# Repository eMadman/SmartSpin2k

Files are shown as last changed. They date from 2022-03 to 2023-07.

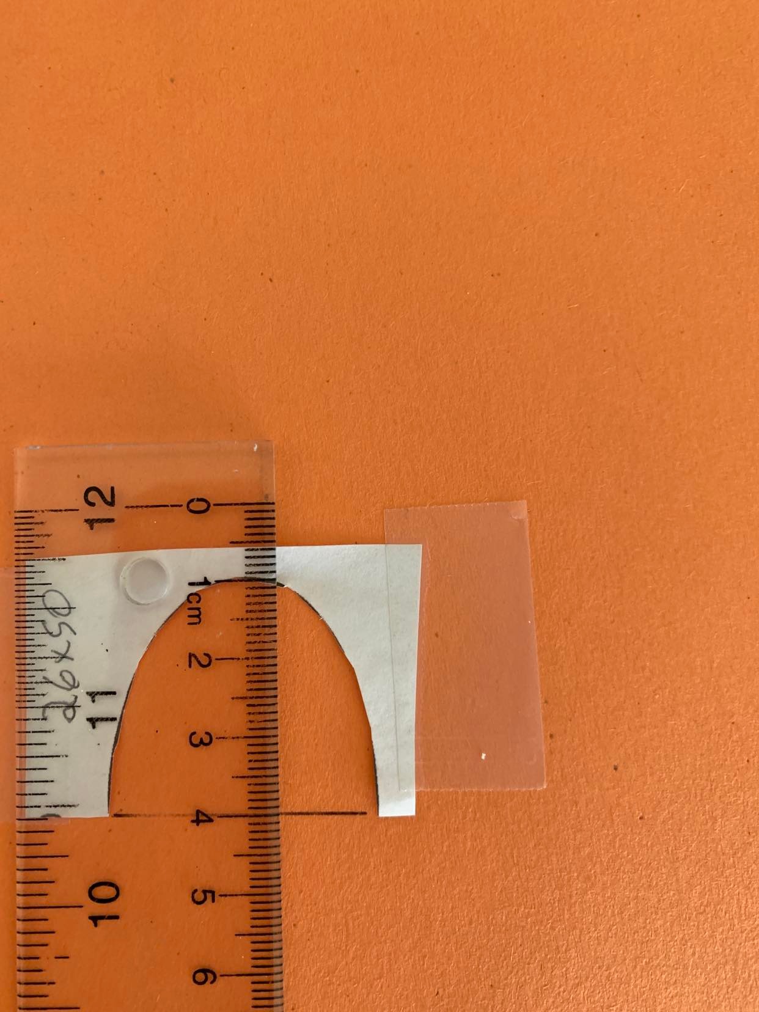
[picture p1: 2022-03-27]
Hardware/MODS/Direct Mount Mod/Bike Mount/reference photos/LeMond Revmaster/cut to fit 2.jpg

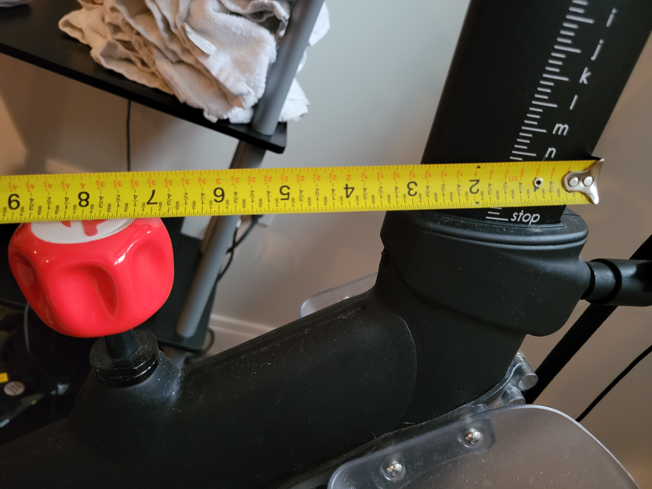
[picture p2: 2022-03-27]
Hardware/MODS/Direct Mount Mod/Bike Mount/reference photos/Peloton/20220217_082631.jpg

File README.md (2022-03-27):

ss2k banner

SmartSpin2k is an easy to build open source project that lets you turn any Spin Bike into a Smart Trainer. SmartSpin2k uses an ESP32 and stepper motor to let fitness apps like Zwift automatically control spin bikes that have a resistance knob. The SmartSpin2k also has shifter buttons that allow the user to simulate shifting gears on the stationary bike. 

Since SmartSpin2k is easy to manufacture, build one for yourself, build some for your friends, or setup a print farm and build them for everybody - we're an open community and welcome all levels of involvement!

## Important announcement for existing users
We have identified an issue with auto updates.  After a factory reset, you will not be able to access the configuration screen.  We advise users to flash the latest version of the 2.2.8 firmware, [available here](https://github.com/doudar/SmartSpin2k/releases).  Flashing instructions are available on the [Wiki](https://github.com/doudar/SmartSpin2k/wiki/Loading-Software)

### Documentation
Everything you need to know is in the [SS2K Wiki](https://github.com/doudar/SmartSpin2k/wiki)

If you'd like to get involved in SS2K but don't want to build your own, a limited number of kits are available on sale by our community members.  [Click here](https://github.com/doudar/SmartSpin2k/wiki/Prebuilt-Kits) for more information

Hardware 2.0 

[_^^@eMadman's IC4 model_](https://github.com/doudar/SmartSpin2k/tree/develop/Hardware/MODS/Case%20V2%20-%20Schwinn%20IC4%20Mod)

## Contributing
1. Install Microsoft Visual Code. https://code.visualstudio.com/
2. Install PlatformIO into Visual Code. https://platformio.org/platformio-ide
3. Install Pre-commit. https://pre-commit.com
4. Install pre-push git hooks: `pre-commit install --hook-type pre-push`
5. Open this project in PlatformIO.

## Licensing
The hardware designs in this project are licensed under the [CERN Open Hardware License Version 2 - Permissive license](Hardware/LICENSE).
The software in this project is licensed under the [GNU GENERAL PUBLIC LICENSE Version 2, June 1991 license](LICENSE).

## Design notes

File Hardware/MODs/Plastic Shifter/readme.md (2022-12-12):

Required hardware:

* 4x M3x20
* 4x heatset inserts - 5mm diameter
* 2x 12mm momentary shifters
* 1x Female headphone connector
* 1x Male to Male headphone cable
* 2x 1/4" velcro straps

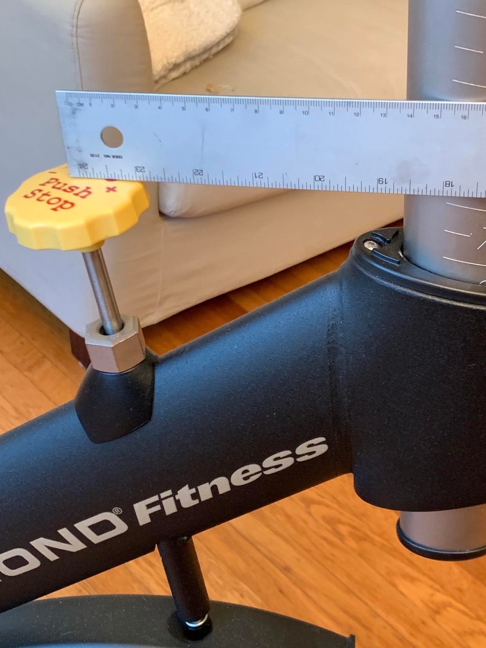
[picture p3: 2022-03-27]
Hardware/MODS/Direct Mount Mod/Bike Mount/reference photos/LeMond Revmaster/273752718_268677505408959_7329679807537366636_n.jpg

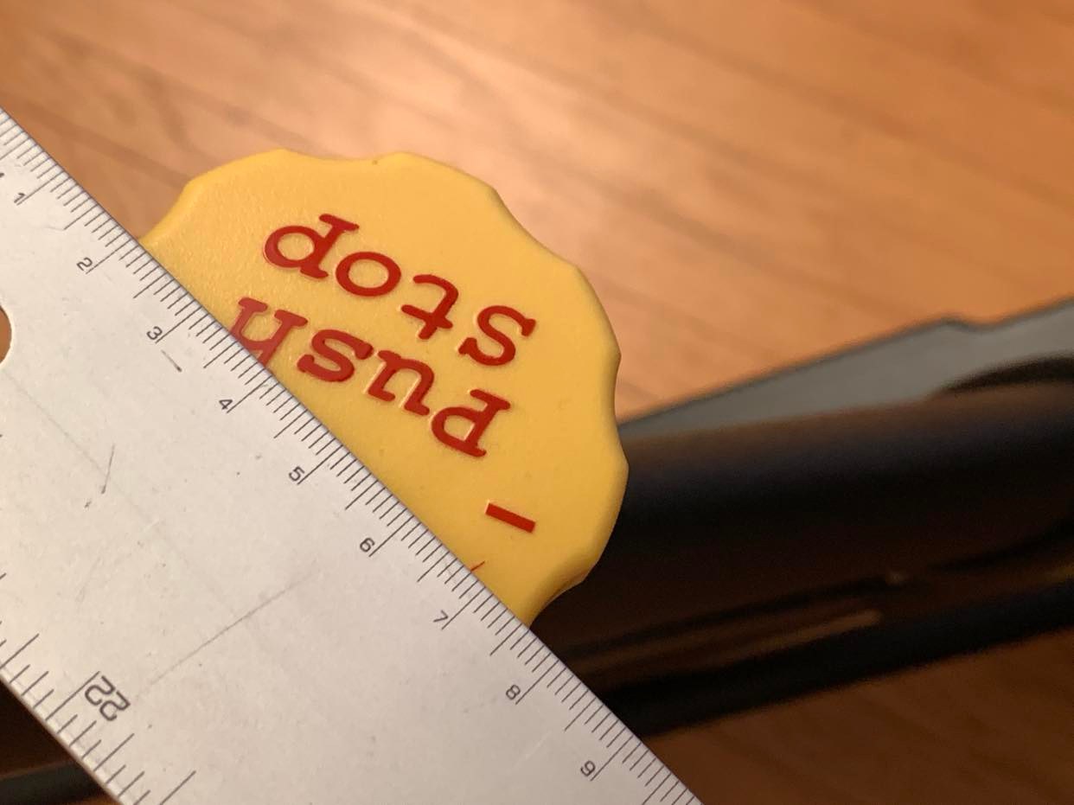
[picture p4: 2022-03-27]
Hardware/MODS/Direct Mount Mod/Bike Mount/reference photos/LeMond Revmaster/259313492_315241787087385_651882542709975977_n.jpg

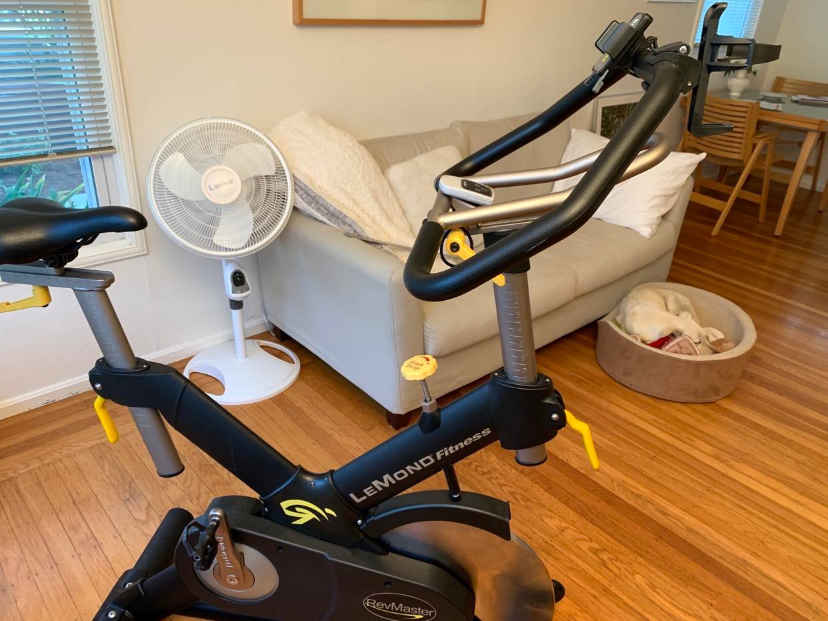
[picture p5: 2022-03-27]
Hardware/MODS/Direct Mount Mod/Bike Mount/reference photos/LeMond Revmaster/272849360_1012936169320139_2908520262834072954_n.jpg

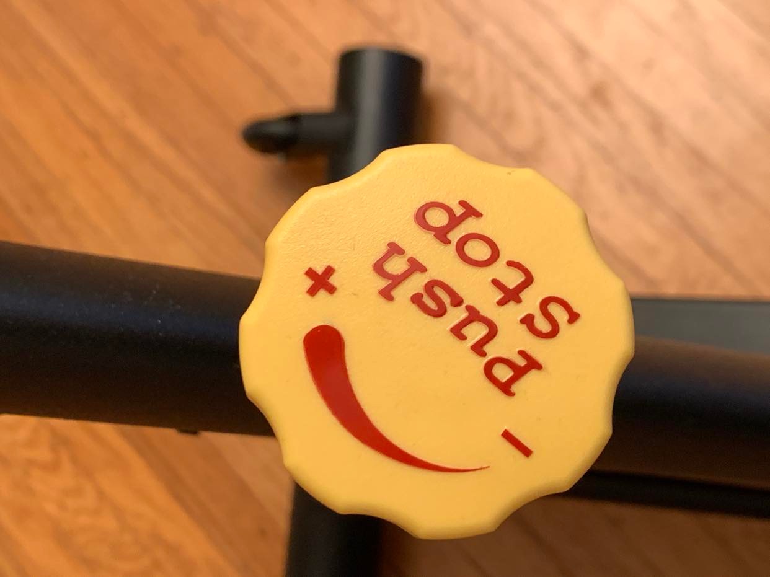
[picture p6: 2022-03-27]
Hardware/MODS/Direct Mount Mod/Bike Mount/reference photos/LeMond Revmaster/270647746_495659278598530_319794024257236569_n.jpg

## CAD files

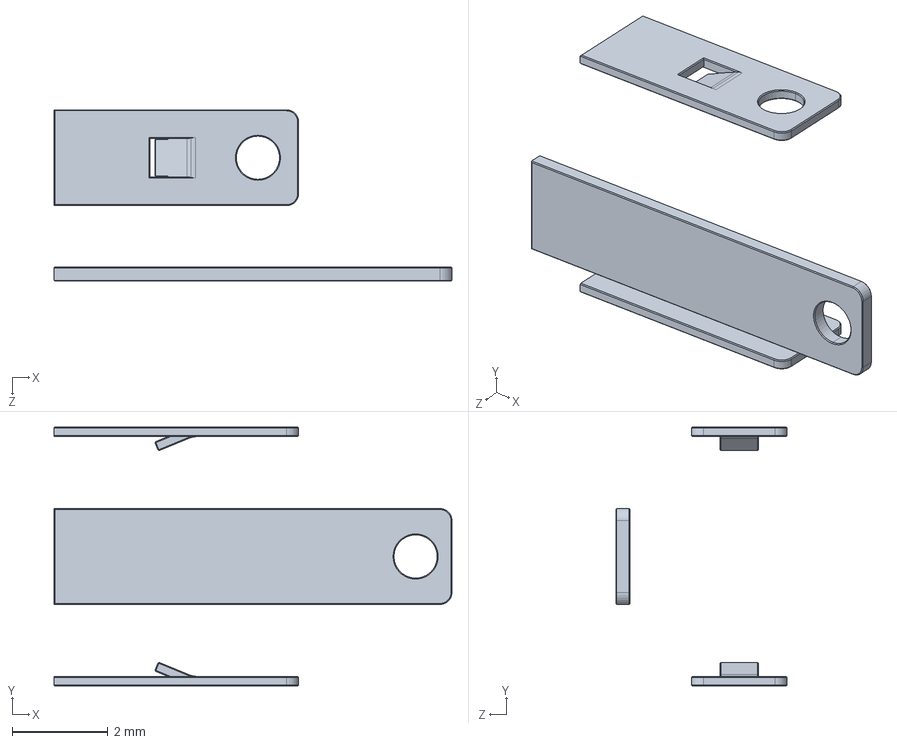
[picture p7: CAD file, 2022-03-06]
Hardware/MODS/Case V2 - Ultra Short Mod/Case/CAD/Connectors/3.5mmJack.SLDASM
8.30 x 5.40 x 3.58 mm

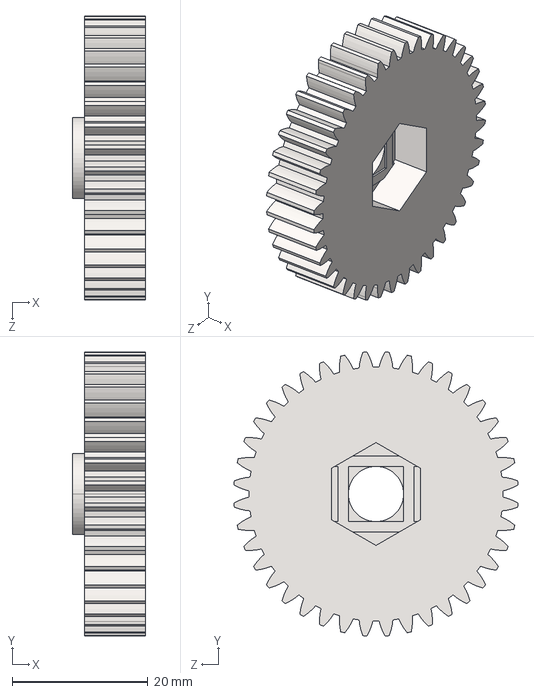
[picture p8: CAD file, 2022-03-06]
Hardware/Case Version2/Gears/CAD/Spur gear 1M 40T Hex.STEP
10.8 x 41.9 x 41.9 mm

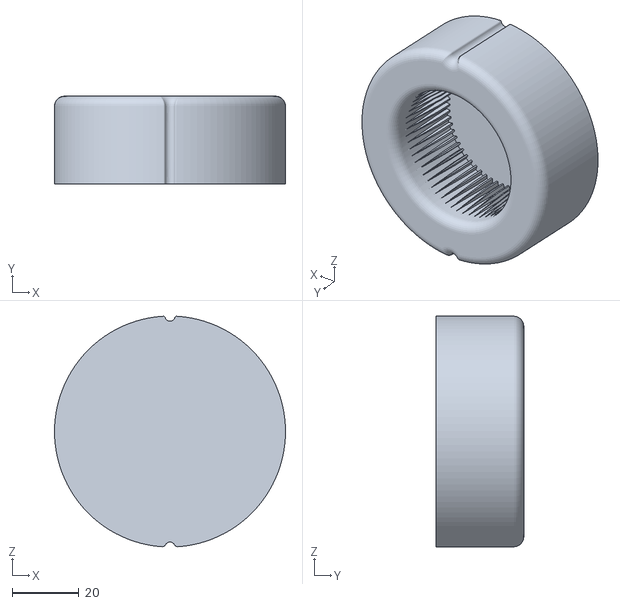
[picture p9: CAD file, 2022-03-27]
Hardware/Inserts/Star Trac 2010.stl
69.0 x 26.2 x 68.9

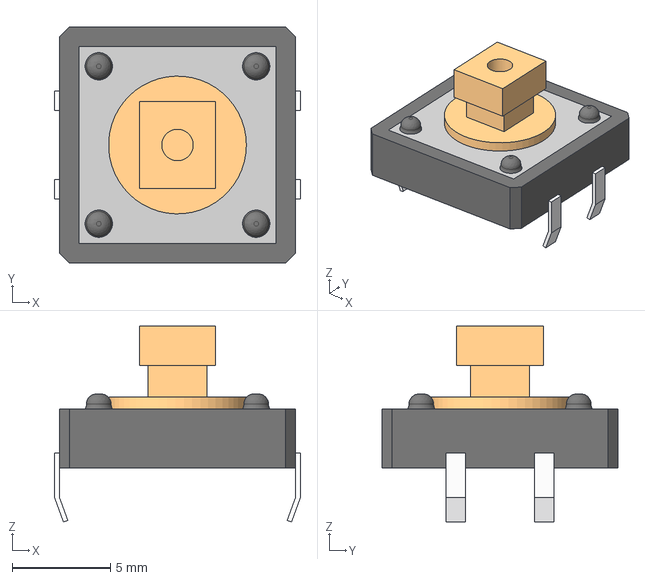
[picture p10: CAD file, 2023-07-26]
Hardware/MODS/39.4mm motor/Case/Case/CAD/PCB Switch 01.step
12.5 x 12.0 x 9.95 mm

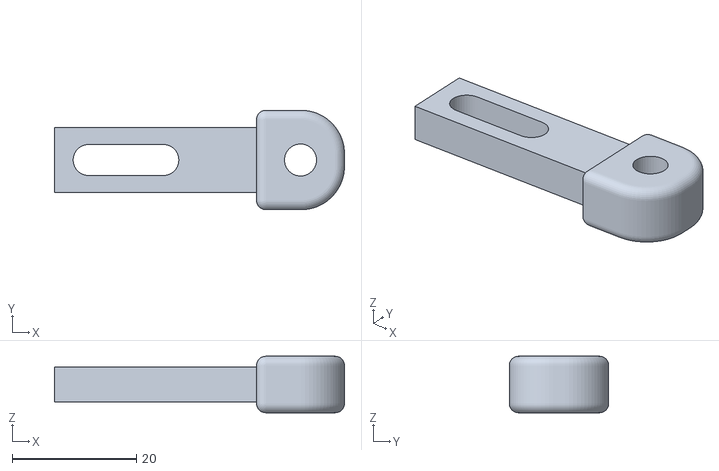
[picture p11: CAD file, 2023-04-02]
Hardware/MODS/Adjustable Arm/Bowflex C7.stl
46.7 x 16.0 x 9.10

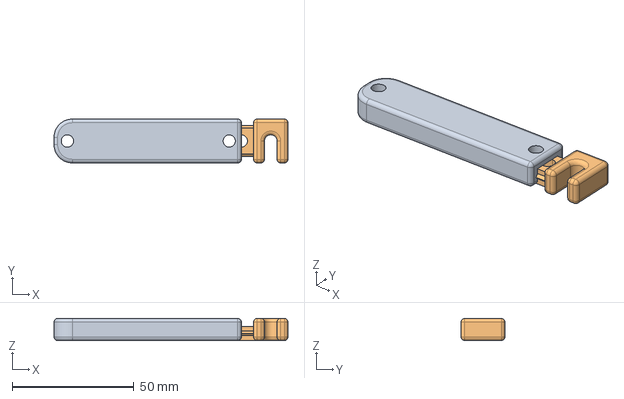
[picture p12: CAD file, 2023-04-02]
Hardware/MODS/Adjustable Arm/CAD/Peloton.step
96.2 x 18.0 x 9.10 mm

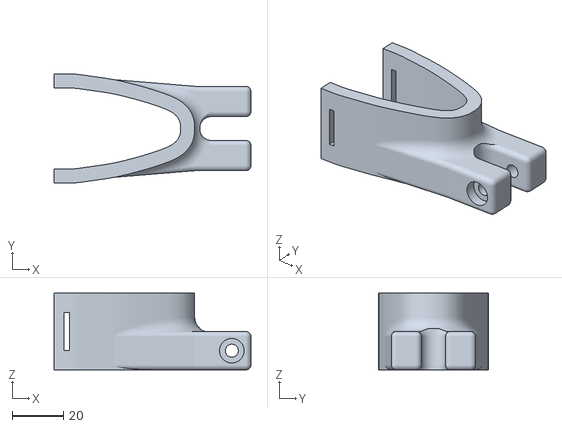
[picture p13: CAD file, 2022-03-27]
Hardware/MODS/Direct Mount Mod/Bike Mount/Peloton.stl
77.0 x 42.8 x 30.0

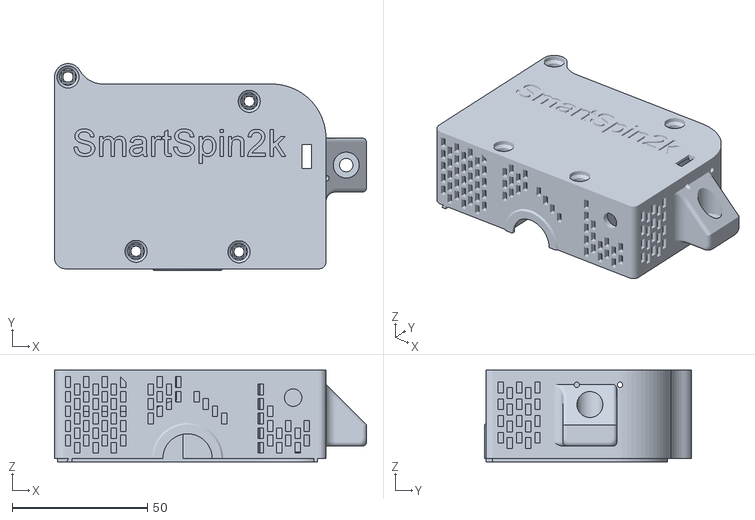
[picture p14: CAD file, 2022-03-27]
Hardware/MODS/Direct Mount Mod/Case/body-right.stl
115.5 x 76.6 x 33.9

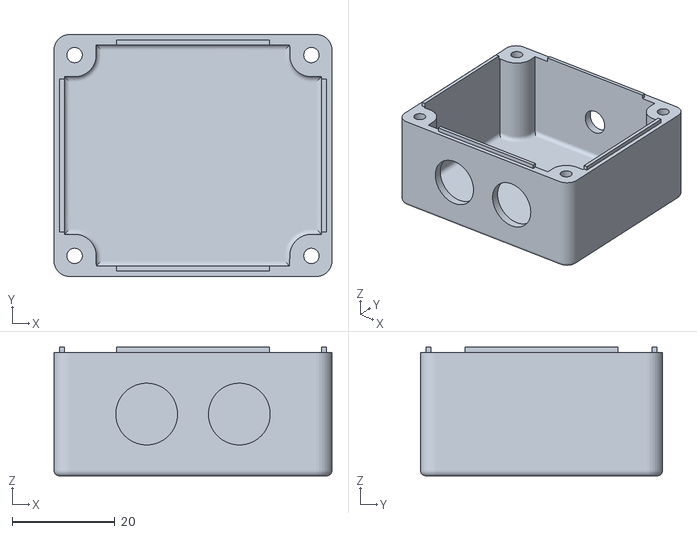
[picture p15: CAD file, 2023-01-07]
Hardware/MODs/Plastic Shifter/Body.stl
54.0 x 47.0 x 25.0

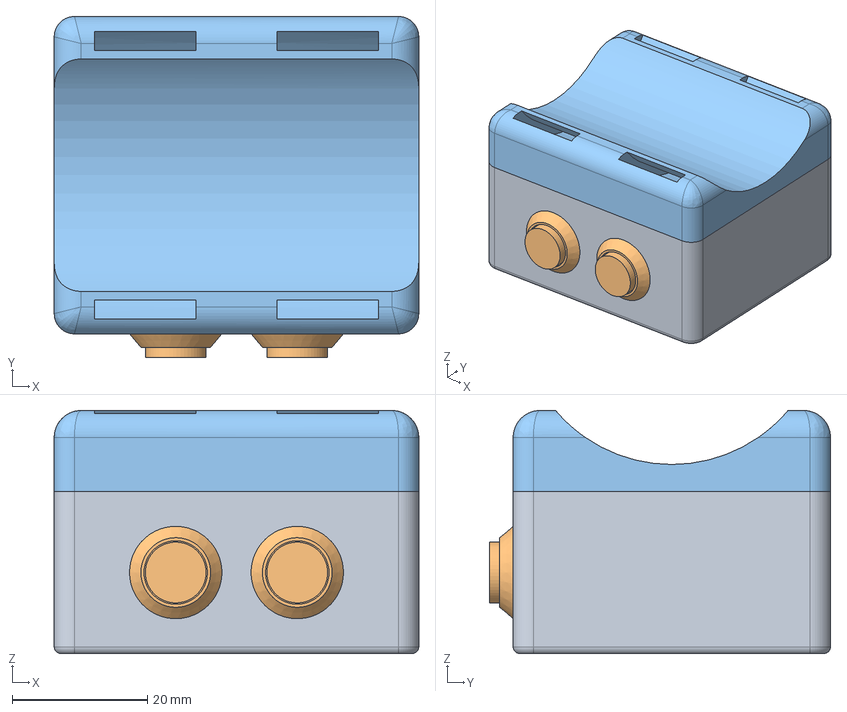
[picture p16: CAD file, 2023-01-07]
Hardware/MODs/Plastic Shifter/CAD/ABS Shifter v9.step
54.0 x 50.5 x 36.0 mm
Button
lid

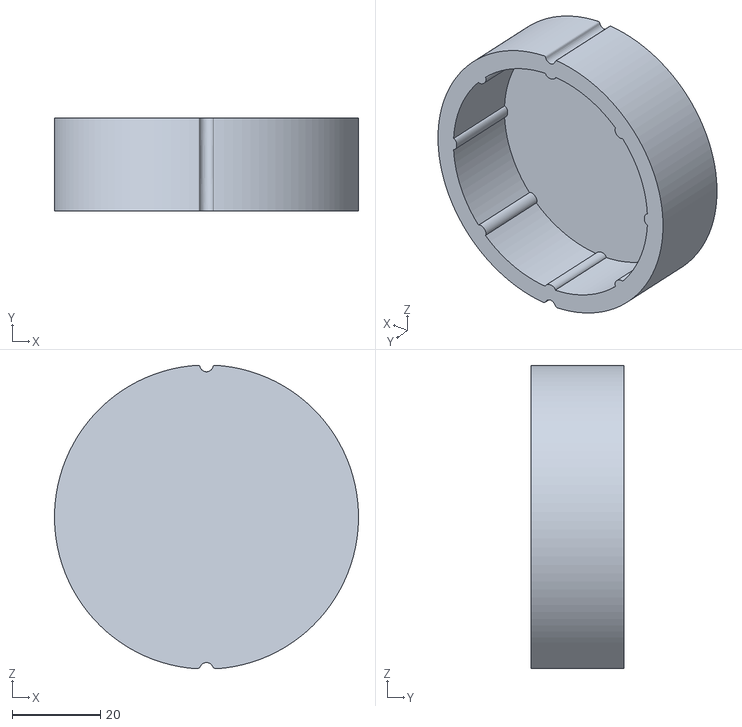
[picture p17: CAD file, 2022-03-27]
Hardware/Inserts/Le Mond Revmaster.stl
69.0 x 21.2 x 68.9

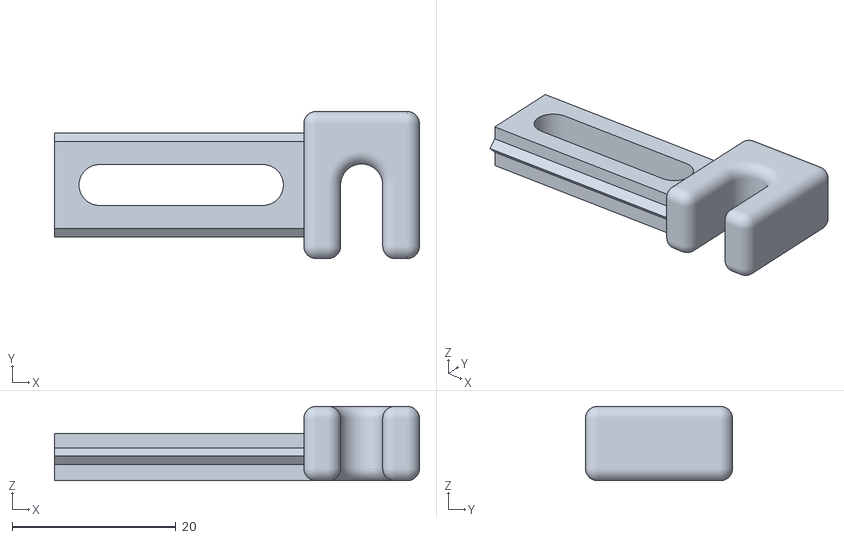
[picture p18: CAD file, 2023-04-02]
Hardware/MODS/Adjustable Arm/_arm hook.stl
44.7 x 18.0 x 9.10

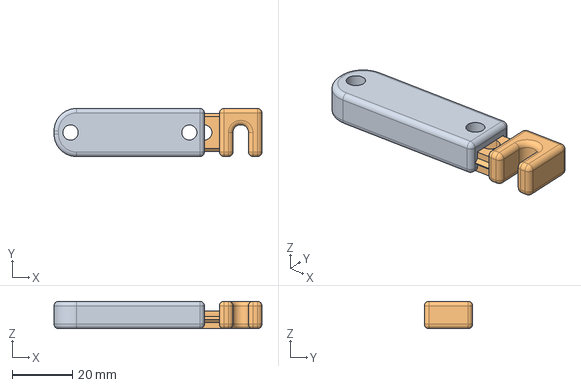
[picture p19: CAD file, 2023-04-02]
Hardware/MODS/Adjustable Arm/CAD/_ss2k arm - reference v4 v7.step
69.2 x 16.0 x 9.10 mm

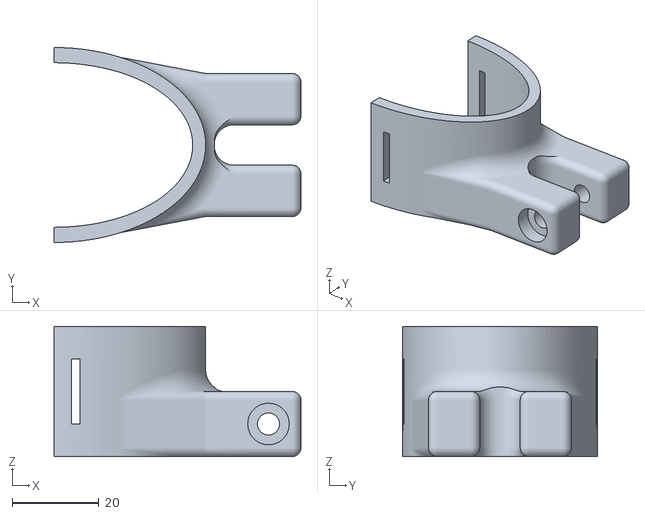
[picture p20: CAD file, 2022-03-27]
Hardware/MODS/Direct Mount Mod/Bike Mount/LeMond Promaster.stl
57.0 x 45.0 x 30.0

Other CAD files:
Hardware/MODS/39.4mm motor/Case/Case/CAD/Connectors/54-00063_ASM.SLDASM
Hardware/MODS/39.4mm motor/Case/Case/CAD/Connectors/3.5mmJack.SLDASM
Hardware/MODS/39.4mm motor/Case/Case/CAD/Connectors/54-00063-4.SLDPRT
Hardware/MODS/39.4mm motor/Case/Case/CAD/Connectors/54-00063-8.SLDPRT
Hardware/Case Version2/Gears/CAD/Spur gear 1M 40T Hex.SLDPRT
Hardware/Case Version2/Gears/Spur gear 1M 40T Hex.STL
Hardware/MODS/39.4mm motor/Case/Case/CAD/Body_Drawing.SLDPRT
Hardware/MODS/39.4mm motor/Case/Case/CAD/Body_Drawing_Left.SLDPRT
Hardware/MODS/39.4mm motor/Case/Case/CAD/Body_Drawing_Left.STEP
Hardware/MODS/39.4mm motor/Case/Case/CAD/Body_Drawing_Right.SLDPRT
Hardware/MODS/39.4mm motor/Case/Case/CAD/Body_Drawing_Right.STEP
Hardware/MODS/39.4mm motor/Case/Case/CAD/Connectors/54-00063-1.SLDPRT
Hardware/MODS/39.4mm motor/Case/Case/CAD/Connectors/54-00063-3.SLDPRT
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

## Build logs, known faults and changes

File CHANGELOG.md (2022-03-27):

# Changelog

All notable changes to this project will be documented in this file.

The format is based on [Keep a Changelog](https://keepachangelog.com/en/1.0.0/)
and this project adheres to [Semantic Versioning](https://semver.org/spec/v2.0.0.html).

## [Unreleased]

### Added

- Added a test for wifi connectivity and a function to repair the connection.
- Added a new WIFI_Control class.

-

### Changed

- Pruned a couple unused functions from main.
- Updated to Esp32 Arduino master.
- Changed BLE tasks back to core 1.
- Increased stack size on both BLE tasks as well as the HTTP server task.
- updated CA for OTA updates

### Fixed

### Hardware

- Short Mod, increased screw hole size from 4.0mm to 4.2mm.
- Short Mod, moved plug wall offset from 1.8mm to 2.0mm.
- Increased shaft diameter of 40T hex gear by .15
- Increased bolt head diameter of 40T hex gear by .15
- added chamfer to screw posts in case body (direct mount mod)

## [2.2.8]

### Added

- Added screenshot for wiki main page
- Added functions to start and stop WiFi and Http server.
- Added Additional logging to the custom characteristic.
- Added option to enable/disable UDP logging. Default is disabled.
- Added Wiki links to most SS2K pages. [see #314](https://github.com/doudar/SmartSpin2k/issues/314)
- Added WebSockets for logging [see #173](https://github.com/doudar/SmartSpin2k/issues/173)
- Reworked logging to run log-appender outside the worker task (task no longer blocked by logger traffic).
- WebsocketsAppender can handle multiple (up to 4) clients. Status.html will reconnect if connection to websockets server is disconnected.

### Changed

- Refactored ERG.
- Reset to Default must be confirmed [see #51](https://github.com/doudar/SmartSpin2k/issues/51)
- Update Firmware: Upload dialog accepts .bin, .html and .css files. [see #98](https://github.com/doudar/SmartSpin2k/issues/98)
- Removed conflicting secondary BLE indicate when a shift was preformed via the custom characteristic.
- Default stepper power is now used on reset to defaults.
- Refactored Main and HTTP Server.
- Changed from hard coding to Enums in BLEServer.
- Added simulateWatts to ERG mode internal check.
- Increased BLE Stack(s) and reduced ERG stack.
- Disabled shifter ISR while ERG is running.
- Fixed possible infinite loop in ERG when stepper never reached target position due to being past min or max position.
- When UDP logging is enabled, html will no longer request logging info.
- Increased remote server minimum packet delay to 325ms and max to 700ms.
- Updated Arduino_esp32 to the latest 2.0.2 version.
- Fixed all libraries to static releases.
- Reduced max_connect_retries from 10 to 3.
- Increased max_scan_retries from 1 to 2.
- Now only send notifications for subscribed characteristics.
- Increased JSON size for userConfig (hopefully fix config saving issues).
- Changed LOGE messages in spiffs logging to regular LOG messages so they will display via network logging.
- Complete BLE Client connection code rebase.

### Fixed

- bluetoothscanner.html now lists fitness machine services in the PM list.
- Fixed bug in external control.

### Hardware

- Added Ultra Short Case mod which should allow as little as ~40mm from knob center to head tube.
- Revised shifter for easier printing.  Updated printing instructions.
- moved original shifter design into Archive directory

#### Direct mount Mod

- IC4 Mod renamed to Direct Mount Mod.  Several directories have changed.
- bike mount and arm added for Echelon Connect Sport
- Arm design revised for added stiffness
- Case, arm and bike mount separated into individual CAD files for easier edits.
- Arm and bike mount re-drawn in CAD.  It should be much easier to create designs for new bikes now.
- Added direct mount for Revmaster and Peloton bikes
- New insert for Startrac

## [1.12.30]

### Added

- Added userConfig shifterDir to change direction of shifters in software to compensate for wiring
- Added userConfig StepperDir to change direction of stepper in software to compensate for wiring
- Added backend and html for shifter and stepper directions.
- Added parameters for auto homing.

### Changed

- Fixed a couple bugs in PowerTables
- Fixed BLE Scanner webpage not displaying devices.
- Corrected a check in the FTMS write control point indication.
- readme copy change
- added bridging improvements for screw holes - in cad but missing in STL

### Hardware

-

#### IC4 Mod

-

## [1.12.26]

### Added

- Added Webpage for Shifting.
- Added /shift server on backend.
- Split userConfig into userConfig and rtConfig.
- Added ERG testing to btsimulator.html
- Broke out ERG computation into it's own task.
- Added image for wiki.
- Replaced existing shifter housing with new and improved 2 in 1 revision

### Changed

- Adjusted the order of "Submit" "Reboot" and "Reset to Defaults" on the settings page.
- Adjusted the setting webpage so "reset to defaults" is harder to accidentally press.
- Increased the amount of free stack by removing the default Arduino loop();
- Updated /shift server on to rtConfig.
- Fixed redeclaring global targetposition in moveStepper().
- Renamed Settings page "Submit" button to "Save Setting"

### Hardware

- Increased hex head and nut size to 13mm.
- Increased depth on Knob Cup 2mm so a thicker nut can be used.
- Added assembly .gif images.

#### IC4 Mod

- NEW: Hex bolt mod for 40t gear and matching ic4 cup/mount. This is a drop-in replacement for the plastic printed gear + cup/holder combination. This adds a lot of strength
- Renamed directory to something more apparent.
- Removed need for support material from case.
- Thicker slide design which removes need for washers.
- Slightly shorter slide - should allow more flexibility for ss2k placement on IC4.
- Tighter tolerances on case and bike mount for slide fitting. It should be a tight enough to prevent accidental removal
- Slightly larger diameter holes for m3 screws used in case assembly. Screws should be much easier to insert
- Additional tolerance for m5 fitting.
- Combined knob cup & knob insert for schwinn to reduce amount of plastic needed for the schwinn.
- Including a revised 11t stl - A bit more clearance on inner diameter the drive shaft on my steppers.

## [1.12.2]

### Added

- Firmware update will now download only spiffs files if missing without updating the firmware.
- New UDP logger by @MarkusSchneider .
- Added custom IC4 build and mount by @eMadman .

### BugFixes

- Power Correction factor now minimum .5 maximum 2.5 and added checks to stay within limits.
- 404 now redirects to index file handler.
- settings_processor now checks shiftsteps field to determine if it's on the main settings page.

## [1.11.24]

### Added

- Moved FTMS callback decoding outside of the callback.
- Revamped the way notify buffer works as it was causing a memory leak.
- BLE Custom Characteristic motor driver calls now apply settings received.
- Motor current now automatically scales if ESP32 temp starts getting too high.
- Added comments after compiler #endif Statements to make it easier to see what the partner #if statement is.
- Added BLE_syncMode to support syncing shifterPosition with bikes that also report their resistance level.
- Added git tag to prevent branch from downgrading to the last release.
- Added Hardware Version 2.0.
- MCWPWM for stepper control.
- Erg Sensitivity control added.
- Function to stop motor and release tension if the user stops pedaling in ERG mode.  
- Received BLE is now buffered and then processed.
- Added Fitness Machine supported inclination range characteristic.
- Additional unit tests.

### Changed

- Renamed BLE_stepperPosition to BLE_targetPosition to clarify the variable it controls.
- Increased BLE communications task to 3500 stack.
- Fixed recurring debugging line when driver was at normal temp.
- Fixed length of returnValue on custom BLE bool read requests.

## [1.6.19] - 2021-6-19

### Added

- Initial implementation of the custom characteristic.
- Added additional FTMS characteristics and some refactoring of shared variables
- Added GZipped jQuery to fix non WAN connected manual updates.
- Pin arduino-esp32 package to version 1.0.6 to fix build issue
- Added + - Buttons to sliders.
- Added firmware checklist to "~/" for PR and release candidate testing.
- Added README.md to "~/Hardware/*" that provides help for the files contained within.
- Added BakerEchelonStrap to "~/Hardware/Mounts/".
- Added positive retention clip to "~/Hardware/Mounts".
- Added Logan clip to "~/Hardware/Mounts".
- Added experimental rigid mounting strap. * Fixed width to 65mm.
- Add images for video links in Wiki Build How To.
- Added webhook for simulated cadence.
- Add image for video link in Build How To
- Added images for video links in Wiki Build How To
- Added XL (Extra Long) Mounting strap for Echelon.
- Added Insert Peloton 7 Flat V2 .sldpart and .stl.
- Added initial credits file.
- Added initial changelog.
- Enabled cpp-lint, pio check, and clang-format to enforce coding standards and catch errors.
- Added support for ruing pre-commit to run pre-push checks.
- Added github workflow on pull_request to validate changelog and coding standards.
- Add hyphens to Flywheel GATT UUIDs.
- Filter Flywheel advertisements by name.
- Added unit tests for CyclePowerData.cpp
- Add documentation to SensorData class.
- Enabled native testing.
- Added logging library which supports levels.

### Changed

- Moved Vin to the correct side on the ESP32 connection diagram.
- Power Correction Factor minimum value is now .5
- Made Revmaster insert slightly smaller.
- Fixed minor spulling errurs.
- Reorganized hardware library into per part subfolders.
- Updater shifter cover to version 9.
- Fixed missing strap loops on non-pcb case.
- Power Correction Factor slider now updates correctly.
- Removed unused http onServer calls.
- Repaired btsimulator.html
- Shortened HR characteristic to 2 bytes (Polar OH1 format)
- Increased ShiftStep UI slider range.
- Replaced DoublePower setting with PowerCorrectionFactor setting.
- Reverted bytes_to_u16 macro.
- Erg mode tweak.
- Added another test for Flywheel BLE name.
- Updated Echelon Insert
- Fixed many issues exposed by the addition of cpp-lint, pio check, and clang-format.
- Fixed merge issues.
- Fixed Echelon licenses.
- Fix Flywheel power/cadence decoding.
- Ignore zero heart rate reported from remote FTMS.
- Fix Assimoa Uno stuck cadence.
- Started extract non-arduino code into a cross-platform library.
- Changed all logging calls to new logging library.

### Removed

- Deleted and ignored .pio folder which had been mistakenly committed.

*1.3.21
- SS2K BLE Server now accepts more than one simultaneous connection (you can not connect SS2K to both Zwift and another app simultaneously)
- Echelon bike is now supported
- SmartSpin2K.local more accessible with different browsers (fixed certain MDNS dropouts)
- Flywheel bike support built in (still untested)
- Backend (client) completely revamped to allow more device decoders, better stability, and faster network speeds.
- Lots of FTMS server and client polishing
- Added testing for decoders
- Versioning now comes from releases
- NimBLE library included
- Increased total max connections to 6 devices
- Refined debugging logs

*1.2.15
- Fixed BLE cadence when accumulated torque values are present
- Lowered memory footprint

*1.2.6
- Added limited Telegram BLE debugging information for development. No sensitive information is sent back. I can make this telegram info available as a private group (in Telegram) if anyone is interested in seeing it. This was added because there are a couple BLE devices that don't seem to conform to the standard protocol and we need more information about them to get them to work properly.
- Internal web UI links now use IP address instead of the local DNS name for compatibility with certain routers.
- Added a favorite icon (favicon.ico) for browser compatibility.
- Fixed an BLE bug which would occasionally cause a crash on scanning.
- Changed priority of subroutines and optimized task memory footprint.
- Streamlined the WiFi connect sequence.  

*0.1.1.22
- Power meter will now switch to the most recently connected and disconnect the other.
- Double power option in the Bluetooth scanner webpage.
- Bluetooth scanning now happens via a flag set in the client task.
- Backend of the Bluetooth scanning page revamped.
- Removed dedicated HTTP server callback for the Bluetooth scanner.

*0.1.1.11
- All metrics now zero when correct BLE !connected.
- Added HR->PWR off/auto switch.
- WiFi starts up faster.
- BLE now connects device on save.
- BLE Scans are less error prone.
- MDNS Fix for certain android browsers.
- and probably lots of other stuff.

*0.1.1.2 A new binary version is out in OTAUpdates. Units should automatically update to this newest version.

- Changes:
- WiFi Fallback to AP mode is now 10 seconds.
- WiFi AP mode Fallback SSID is now device name (MDNS name), and the password is whatever you have set.
- ERG Mode slightly more aggressive.
- Stealthchop 2 now selectable in settings.
- Holding both shifters at boot resets the unit to defaults and erases filesystem. (firmware remains intact)
- Holding both shifters for 3 seconds after boot preforms a BLE device scan/reconnect.

- Bugfixes:
- Automatic Updates setting switch now works :)

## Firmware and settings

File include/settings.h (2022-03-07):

/*
 * Copyright (C) 2020  Anthony Doud & Joel Baranick
 * All rights reserved
 *
 * SPDX-License-Identifier: GPL-2.0-only
 */

#pragma once

#include "SS2KLog.h"

// Update firmware on boot?
#define AUTO_FIRMWARE_UPDATE true

// Default Bluetooth WiFi and MDNS Name
#define DEVICE_NAME "SmartSpin2K"

// Default WiFi Password
#define DEFAULT_PASSWORD "password"

// default URL To get Updates From.
// If changed you'll also need to get a root certificate from the new server
// and put it in /include/cert.h
#define FW_UPDATEURL "https://raw.githubusercontent.com/doudar/OTAUpdates/main/"

// File that contains Version info
#define FW_VERSIONFILE "version.txt"

// Path to the latest Firmware
#define FW_BINFILE "firmware.bin"

// Path to the latest filesystem
#define FW_SPIFFSFILE "spiffs.bin"

// name of local file to save configuration in SPIFFS
#define configFILENAME "/config.txt"

// name of local file to save Physical Working Capacity in Spiffs
#define userPWCFILENAME "/userPWC.txt"

// Default Incline Multiplier.
// Incline multiplier is the multiple required to convert incline received from the remote client (percent grade*100)
// into actual stepper steps that move the stepper motor. It takes 2,181.76 steps to rotate the knob 1 full revolution. with hardware version 1.
// Incline_Multiplier may be able to be removed in the future by dividing ShiftSteps by ~200 to get this value but we're not quite ready
// to make that commitment yet.
#define INCLINE_MULTIPLIER 3.0

// Minumum value for power correction factor user setting
#define MIN_PCF .5

// Maximum value for power correction factor user setting
#define MAX_PCF 2.5

// Default Stepper Power.
// Stepper peak current in ma. This is hardware restricted to a maximum of 2000ma on the TMC2225. RMS current is less.
#define DEFAULT_STEPPER_POWER 1500

// Default Shift Step. THe amount to move the stepper motor for a shift press.
#define DEFAULT_SHIFT_STEP 1000

// Stepper Acceleration in steps/s^2
#define STEPPER_ACCELERATION 3000

// Stepper Max Speed in steps/s
#define STEPPER_SPEED 1500

// Stepper Max Speed in ERG Mode steps/s
#define STEPPER_ERG_SPEED 1500

// Default ERG Sensitivity. Predicated on # of Shifts (further defined by shift steps) per 30 watts of resistance change.
// I.E. If the difference between ERG target and Current watts were 30, and the Shift step is defined as 600 steps,
// and ERG_Sensitivity were 1.0, ERG mode would move the stepper motor 600 steps to compensate. With an ERG_Sensitivity of 2.0, the stepper
// would move 1200 steps to compensate, however ERG_Sensitivity values much different than 1.0 imply shiftStep has been improperly configured.
#define ERG_SENSITIVITY 1.0

// Number of watts per shift expected by ERG mode for it's calculation. The user should target this number by adjusting Shift Step until WATTS_PER_SHIFT
// is obtained as closely as possible during each shift.
#define WATTS_PER_SHIFT 15

// Default Max Watts that the brake on the spin bike can absorb from the user.
#define DEFAULT_MAX_WATTS 700

// Wattage at which to automatically assume minimum brake resistance.  
#define MIN_WATTS 35

// Default debounce delay for shifters. Increase if you have false shifts. Decrease if shifting takes too long. 
#define DEBOUNCE_DELAY 400

// Hardware pin for rocker Switch
#define RADIO_PIN 27

// Hardware pin for Shift Up
#define SHIFT_UP_PIN 19

// Hardware pin for Shift Down
#define SHIFT_DOWN_PIN 18

// Hardware pin for stepper Enable
#define ENABLE_PIN 13

// Hardware pin for stepper step
#define STEP_PIN 25

// Hardware pin for stepper dir
#define DIR_PIN 33

// TMC2208/TMC2224 SoftwareSerial receive pin
#define STEPPERSERIAL_RX 14

// TMC2208/TMC2224 SoftwareSerial transmit pin
#define STEPPERSERIAL_TX 12

// TMC2208/TMC2224 HardwareSerial port
#define SERIAL_PORT stepperSerial

// Match to your driver
#define R_SENSE 0.11f

// Maximum scaling of the driver output power 0-31
#define DRIVER_MAX_PWR_SCALER 31

// Hardware pin for indicator LED *note* internal LED on esp32 Dev board is pin
// 2
#define LED_PIN 2

// Max tries that BLE client will perform on reconnect
#define MAX_RECONNECT_TRIES 3

// When quick reconnect fails ^^, we try to scan for the disconnected server.
// Scans slow BLE & WiFi traffic so we don't want to do this forever.
// Give up scanning for the lost connection after this many tries:
#define MAX_SCAN_RETRIES 2

// loop speed for the SmartSpin2k BLE communications
#define BLE_NOTIFY_DELAY 700

// loop speed for the SmartSpin2k BLE Client reconnect
#define BLE_CLIENT_DELAY 1000

// Number of devices that can be connected to the Client (myBLEDevices size)
#define NUM_BLE_DEVICES 4

// loop speed for the Webserver
#define WEBSERVER_DELAY 60

// Name of default Power Meter. any connects to anything, none connects to
// nothing.
#define CONNECTED_POWER_METER "any"

// Name of default heart monitor. any connects to anything, none connects to
// nothing.
#define CONNECTED_HEART_MONITOR "any"

// number of main loops the shifters need to be held before a BLE scan is
// initiated.
#define SHIFTERS_HOLD_FOR_SCAN 2

// stealthchop enabled by default
#define STEALTHCHOP true

// how long to try STA mode before falling back to AP mode
#define WIFI_CONNECT_TIMEOUT 10

// Max size of userconfig
#define USERCONFIG_JSON_SIZE 1024 + DEBUG_LOG_BUFFER_SIZE

#define RUNTIMECONFIG_JSON_SIZE 512 + DEBUG_LOG_BUFFER_SIZE

// Number of entries in the ERG Power Lookup Table
#define POWERTABLE_SIZE 20

// Size of increments (in watts) for the ERG Lookup Table. Needs to be one decimal place for proper calculations i.e. 50.0
#define POWERTABLE_INCREMENT 25.0

//Number of similar power samples to take before writing to the Power Table
#define POWER_SAMPLES 5 

// Uncomment to enable sending Telegram debug messages back to the chat
// specified in telegram_token.h
// #define USE_TELEGRAM

// Uncomment to enable stack size debugging info
//#define DEBUG_STACK

// Uncomment to enable HR->PWR debugging info. Always displays HR->PWR
// Calculation. Never sets userConfig.setSimulatedPower(); #define
// DEBUG_HR_TO_PWR

#ifdef USE_TELEGRAM
// Max number of telegram messages to send per session
#define MAX_TELEGRAM_MESSAGES 1
// Filler definitions for if telegram_token.h is not included (because it has
// sensitive information). Do not change these as this file is tracked and
// therefore public. Enter your own Telegram info into telegram_token.h
#if __has_include("telegram_token.h")
#include "telegram_token.h"
#else
#define TELEGRAM_TOKEN   "1234567890:ABCDEFGHIJKLMNOPQRSTUVWXYZabcdefghi"
#define TELEGRAM_CHAT_ID "1234567890"
#endif
#endif

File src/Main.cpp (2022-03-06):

/*
 * Copyright (C) 2020  Anthony Doud & Joel Baranick
 * All rights reserved
 *
 * SPDX-License-Identifier: GPL-2.0-only
 */

#include "Main.h"
#include "SS2KLog.h"
#include <TMCStepper.h>
#include <Arduino.h>
#include <SPIFFS.h>
#include <HardwareSerial.h>
#include "FastAccelStepper.h"
#include "ERG_Mode.h"
#include "UdpAppender.h"
#include "WebsocketAppender.h"

HardwareSerial stepperSerial(2);
TMC2208Stepper driver(&SERIAL_PORT, R_SENSE);  // Hardware Serial
FastAccelStepperEngine engine = FastAccelStepperEngine();
FastAccelStepper *stepper     = NULL;
// Setup a task so the stepper will run on a different core than the main code
// to prevent stuttering
TaskHandle_t moveStepperTask;
TaskHandle_t maintenanceLoopTask;

///////////// Initialize the Config /////////////
SS2K ss2k;
userParameters userConfig;
RuntimeParameters rtConfig;
physicalWorkingCapacity userPWC;

///////////// Log Appender /////////////
UdpAppender udpAppender;
WebSocketAppender webSocketAppender;

///////////// BEGIN SETUP /////////////
#ifndef UNIT_TEST

void SS2K::startTasks() {
  SS2K_LOG(MAIN_LOG_TAG, "Start BLE + ERG Tasks");
  if (BLECommunicationTask == NULL) {
    setupBLE();
  }
  if (ErgTask == NULL) {
    setupERG();
  }
}

void SS2K::stopTasks() {
  SS2K_LOG(MAIN_LOG_TAG, "Stop BLE + ERG Tasks");
  if (BLECommunicationTask != NULL) {
    vTaskDelete(BLECommunicationTask);
  }
  if (ErgTask != NULL) {
    vTaskDelete(ErgTask);
  }
}

void setup() {
  // Serial port for debugging purposes
  Serial.begin(512000);
  stepperSerial.begin(57600, SERIAL_8N2, STEPPERSERIAL_RX, STEPPERSERIAL_TX);
  SS2K_LOG(MAIN_LOG_TAG, "Compiled %s%s", __DATE__, __TIME__);

  // Initialize SPIFFS
  SS2K_LOG(MAIN_LOG_TAG, "Mounting Filesystem");
  if (!SPIFFS.begin(true)) {
    SS2K_LOG(MAIN_LOG_TAG, "An Error has occurred while mounting SPIFFS");
    // TODO reset flash here
    return;
  }

  // Load Config
  userConfig.loadFromSPIFFS();
  userConfig.printFile();  // Print userConfig.contents to serial
  userConfig.saveToSPIFFS();

  // load PWC for HR to Pwr Calculation
  userPWC.loadFromSPIFFS();
  userPWC.printFile();
  userPWC.saveToSPIFFS();

  pinMode(RADIO_PIN, INPUT_PULLUP);
  pinMode(SHIFT_UP_PIN, INPUT_PULLUP);    // Push-Button with input Pullup
  pinMode(SHIFT_DOWN_PIN, INPUT_PULLUP);  // Push-Button with input Pullup
  pinMode(LED_PIN, OUTPUT);
  pinMode(ENABLE_PIN, OUTPUT);
  pinMode(DIR_PIN, OUTPUT);   // Stepper Direction Pin
  pinMode(STEP_PIN, OUTPUT);  // Stepper Step Pin
  digitalWrite(ENABLE_PIN,
               HIGH);  // Should be called a disable Pin - High Disables FETs
  digitalWrite(DIR_PIN, LOW);
  digitalWrite(STEP_PIN, LOW);
  digitalWrite(LED_PIN, LOW);

  ss2k.setupTMCStepperDriver();

  SS2K_LOG(MAIN_LOG_TAG, "Setting up cpu Tasks");
  disableCore0WDT();  // Disable the watchdog timer on core 0 (so long stepper
                      // moves don't cause problems)

  xTaskCreatePinnedToCore(SS2K::moveStepper,     /* Task function. */
                          "moveStepperFunction", /* name of task. */
                          1500,                  /* Stack size of task */
                          NULL,                  /* parameter of the task */
                          18,                    /* priority of the task */
                          &moveStepperTask,      /* Task handle to keep track of created task */
                          0);                    /* pin task to core */

  digitalWrite(LED_PIN, HIGH);

  WiFiControl.start();

  // Configure and Initialize Logger
  logHandler.addAppender(&webSocketAppender);
  logHandler.addAppender(&udpAppender);
  logHandler.initialize();

  // Check for firmware update. It's important that this stays before BLE &
  // HTTP setup because otherwise they use too much traffic and the device
  // fails to update which really sucks when it corrupts your settings.

  httpServer.FirmwareUpdate();

  ss2k.startTasks();
  httpServer.start();

  ss2k.resetIfShiftersHeld();
  SS2K_LOG(MAIN_LOG_TAG, "Creating Shifter Interrupts");
  // Setup Interrups so shifters work anytime
  attachInterrupt(digitalPinToInterrupt(SHIFT_UP_PIN), ss2k.shiftUp, CHANGE);
  attachInterrupt(digitalPinToInterrupt(SHIFT_DOWN_PIN), ss2k.shiftDown, CHANGE);
  digitalWrite(LED_PIN, HIGH);

  xTaskCreatePinnedToCore(SS2K::maintenanceLoop,     /* Task function. */
                          "maintenanceLoopFunction", /* name of task. */
                          3500,                      /* Stack size of task */
                          NULL,                      /* parameter of the task */
                          1,                         /* priority of the task */
                          &maintenanceLoopTask,      /* Task handle to keep track of created task */
                          1);                        /* pin task to core */
}

void loop() {  // Delete this task so we can make one that's more memory efficient.
  vTaskDelete(NULL);
}

void SS2K::maintenanceLoop(void *pvParameters) {
  static int loopCounter              = 0;
  static unsigned long intervalTimer  = millis();
  static unsigned long intervalTimer2 = millis();
  static bool isScanning              = false;

  while (true) {
    vTaskDelay(200 / portTICK_RATE_MS);
    if (rtConfig.getShifterPosition() > ss2k.lastShifterPosition) {
      SS2K_LOG(MAIN_LOG_TAG, "Shift UP: %l", rtConfig.getShifterPosition());
      Serial.println(ss2k.targetPosition);
      spinBLEServer.notifyShift();
    } else if (rtConfig.getShifterPosition() < ss2k.lastShifterPosition) {
      SS2K_LOG(MAIN_LOG_TAG, "Shift DOWN: %l", rtConfig.getShifterPosition());
      Serial.println(ss2k.targetPosition);
      spinBLEServer.notifyShift();
    }
    ss2k.lastShifterPosition = rtConfig.getShifterPosition();
    webSocketAppender.Loop();

    if ((millis() - intervalTimer) > 500) {
      logHandler.writeLogs();
      intervalTimer = millis();
    }

    if ((millis() - intervalTimer2) > 6000) {
      if (NimBLEDevice::getScan()->isScanning()) {  // workaround to prevent occasional runaway scans
        if (isScanning == true) {
          SS2K_LOG(MAIN_LOG_TAG, "Forcing Scan to stop.");
          NimBLEDevice::getScan()->stop();
          isScanning = false;
        } else {
          isScanning = true;
        }
      }

      intervalTimer2 = millis();
    }
    if (loopCounter > 4) {
      ss2k.scanIfShiftersHeld();
      ss2k.checkDriverTemperature();

#ifdef DEBUG_STACK
      Serial.printf("Step Task: %d \n", uxTaskGetStackHighWaterMark(moveStepperTask));
      Serial.printf("Shft Task: %d \n", uxTaskGetStackHighWaterMark(maintenanceLoopTask));
      Serial.printf("Free Heap: %d \n", ESP.getFreeHeap());
      Serial.printf("Best Blok: %d \n", heap_caps_get_largest_free_block(MALLOC_CAP_8BIT));
#endif  // DEBUG_STACK
      loopCounter = 0;
    }
    loopCounter++;
  }
}
#endif  // UNIT_TEST

void SS2K::moveStepper(void *pvParameters) {
  engine.init();
  bool _stepperDir = userConfig.getStepperDir();
  stepper          = engine.stepperConnectToPin(STEP_PIN);
  stepper->setDirectionPin(DIR_PIN, _stepperDir);
  stepper->setEnablePin(ENABLE_PIN);
  stepper->setAutoEnable(true);
  stepper->setSpeedInHz(STEPPER_SPEED);
  stepper->setAcceleration(STEPPER_ACCELERATION);
  stepper->setDelayToDisable(1000);

  while (1) {
    if (stepper) {
      ss2k.stepperIsRunning = stepper->isRunning();
      if (!ss2k.externalControl) {
        if (rtConfig.getERGMode()) {
          // ERG Mode
          // Shifter not used.
          stepper->setSpeedInHz(STEPPER_ERG_SPEED);
          ss2k.targetPosition = rtConfig.getTargetIncline();
        } else {
          // Simulation Mode
          ss2k.targetPosition = rtConfig.getShifterPosition() * userConfig.getShiftStep();
          ss2k.targetPosition += rtConfig.getTargetIncline() * userConfig.getInclineMultiplier();
        }
      }

      if (ss2k.syncMode) {
        stepper->stopMove();
        vTaskDelay(100 / portTICK_PERIOD_MS);
        stepper->setCurrentPosition(ss2k.targetPosition);
        vTaskDelay(100 / portTICK_PERIOD_MS);
      }

      if ((ss2k.targetPosition >= rtConfig.getMinStep()) && (ss2k.targetPosition <= rtConfig.getMaxStep())) {
        stepper->moveTo(ss2k.targetPosition);
      } else if (ss2k.targetPosition <= rtConfig.getMinStep()) {  // Limit Stepper to Min Position
        stepper->moveTo(rtConfig.getMinStep());
      } else {  // Limit Stepper to Max Position
        stepper->moveTo(rtConfig.getMaxStep());
      }

      vTaskDelay(100 / portTICK_PERIOD_MS);
      rtConfig.setCurrentIncline((float)stepper->getCurrentPosition());

      if (connectedClientCount() > 0) {
        stepper->setAutoEnable(false);  // Keep the stepper from rolling back due to head tube slack. Motor Driver still lowers power between moves
        stepper->enableOutputs();
      } else {
        stepper->setAutoEnable(true);  // disable output FETs between moves so stepper can cool. Can still shift.
      }

      if (_stepperDir != userConfig.getStepperDir()) {  // User changed the config direction of the stepper wires
        _stepperDir = userConfig.getStepperDir();
        while (stepper->isMotorRunning()) {
          vTaskDelay(100 / portTICK_PERIOD_MS);
        }
        stepper->setDirectionPin(DIR_PIN, _stepperDir);
      }
    }
  }
}

bool IRAM_ATTR SS2K::deBounce() {
  if ((millis() - lastDebounceTime) > debounceDelay) {  // <----------------This should be assigned it's own task and just switch a global bool whatever the reading is at, it's
                                                        // been there for longer than the debounce delay, so take it as the actual current state: if the button state has changed:
    lastDebounceTime = millis();
    return true;
  }

  return false;
}

///////////// Interrupt Functions /////////////
void IRAM_ATTR SS2K::shiftUp() {  // Handle the shift up interrupt IRAM_ATTR is to keep the interrput code in ram always
  if (ss2k.deBounce() && !rtConfig.getERGMode()) {
    if (!digitalRead(SHIFT_UP_PIN)) {  // double checking to make sure the interrupt wasn't triggered by emf
      rtConfig.setShifterPosition(rtConfig.getShifterPosition() - 1 + userConfig.getShifterDir() * 2);
    } else {
      ss2k.lastDebounceTime = 0;
    }  // Probably Triggered by EMF, reset the debounce
  }
}

void IRAM_ATTR SS2K::shiftDown() {  // Handle the shift down interrupt
  if (ss2k.deBounce() && !rtConfig.getERGMode()) {
    if (!digitalRead(SHIFT_DOWN_PIN)) {  // double checking to make sure the interrupt wasn't triggered by emf
      rtConfig.setShifterPosition(rtConfig.getShifterPosition() + 1 - userConfig.getShifterDir() * 2);
    } else {
      ss2k.lastDebounceTime = 0;
    }  // Probably Triggered by EMF, reset the debounce
  }
}

void SS2K::resetIfShiftersHeld() {
  if ((digitalRead(SHIFT_UP_PIN) == LOW) && (digitalRead(SHIFT_DOWN_PIN) == LOW)) {
    SS2K_LOG(MAIN_LOG_TAG, "Resetting to defaults via shifter buttons.");
    for (int x = 0; x < 10; x++) {  // blink fast to acknowledge
      digitalWrite(LED_PIN, HIGH);
      vTaskDelay(200 / portTICK_PERIOD_MS);
      digitalWrite(LED_PIN, LOW);
    }
    for (int i = 0; i < 20; i++) {
      userConfig.setDefaults();
      vTaskDelay(200 / portTICK_PERIOD_MS);
      userConfig.saveToSPIFFS();
      vTaskDelay(200 / portTICK_PERIOD_MS);
    }
    ESP.restart();
  }
}

void SS2K::scanIfShiftersHeld() {
  if ((digitalRead(SHIFT_UP_PIN) == LOW) && (digitalRead(SHIFT_DOWN_PIN) == LOW)) {  // are both shifters held?
    SS2K_LOG(MAIN_LOG_TAG, "Shifters Held %d", shiftersHoldForScan);
    if (shiftersHoldForScan < 1) {  // have they been held for enough loops?
      SS2K_LOG(MAIN_LOG_TAG, "Shifters Held < 1 %d", shiftersHoldForScan);
      if ((millis() - scanDelayStart) >= scanDelayTime) {  // Has this already been done within 10 seconds?
        scanDelayStart += scanDelayTime;
        spinBLEClient.resetDevices();
        spinBLEClient.serverScan(true);
        shiftersHoldForScan = SHIFTERS_HOLD_FOR_SCAN;
        digitalWrite(LED_PIN, LOW);
        SS2K_LOG(MAIN_LOG_TAG, "Scan From Buttons");
      } else {
        SS2K_LOG(MAIN_LOG_TAG, "Shifters Held but timer not up %d", (millis() - scanDelayStart) >= scanDelayTime);
        shiftersHoldForScan = SHIFTERS_HOLD_FOR_SCAN;
        return;
      }
    } else {
      shiftersHoldForScan--;
    }
  }
}

void SS2K::setupTMCStepperDriver() {
  driver.begin();
  driver.pdn_disable(true);
  driver.mstep_reg_select(true);

  uint16_t msread = driver.microsteps();
  SS2K_LOG(MAIN_LOG_TAG, " read:ms=%ud", msread);

  driver.rms_current(userConfig.getStepperPower());  // Set motor RMS current
  driver.microsteps(4);                              // Set microsteps to 1/8th
  driver.irun(DRIVER_MAX_PWR_SCALER);
  driver.ihold((uint8_t)(DRIVER_MAX_PWR_SCALER * .65));  // hold current % 0-DRIVER_MAX_PWR_SCALER
  driver.iholddelay(10);                                 // Controls the number of clock cycles for motor
                                                         // power down after standstill is detected
  driver.TPOWERDOWN(128);
  msread               = driver.microsteps();
  uint16_t currentread = driver.cs_actual();
  SS2K_LOG(MAIN_LOG_TAG, " read:current=%ud", currentread);
  SS2K_LOG(MAIN_LOG_TAG, " read:ms=%ud", msread);

  driver.toff(5);
  bool t_bool = userConfig.getStealthchop();
  driver.en_spreadCycle(!t_bool);
  driver.pwm_autoscale(t_bool);
  driver.pwm_autograd(t_bool);
}

// Applies current power to driver
void SS2K::updateStepperPower() {
  SS2K_LOG(MAIN_LOG_TAG, "Stepper power is now %d", userConfig.getStepperPower());
  driver.rms_current(userConfig.getStepperPower());
}

// Applies current Stealthchop to driver
void SS2K::updateStealthchop() {
  bool t_bool = userConfig.getStealthchop();
  driver.en_spreadCycle(!t_bool);
  driver.pwm_autoscale(t_bool);
  driver.pwm_autograd(t_bool);
  SS2K_LOG(MAIN_LOG_TAG, "Stealthchop is now %d", t_bool);
}

// Checks the driver temperature and throttles power if above threshold.
void SS2K::checkDriverTemperature() {
  static bool overtemp = false;
  if (static_cast<int>(temperatureRead()) > 72) {  // Start throttling driver power at 72C on the ESP32
    uint8_t throttledPower = (72 - static_cast<int>(temperatureRead())) + DRIVER_MAX_PWR_SCALER;
    driver.irun(throttledPower);
    SS2K_LOGW(MAIN_LOG_TAG, "Overtemp! Driver is throttleing down! ESP32 @ %f C", temperatureRead());
    overtemp = true;
  } else if ((driver.cs_actual() < DRIVER_MAX_PWR_SCALER) && !driver.stst()) {
    if (overtemp) {
      SS2K_LOG(MAIN_LOG_TAG, "Temperature is now under control. Driver current reset.");
      driver.irun(DRIVER_MAX_PWR_SCALER);
    }
    overtemp = false;
  }
}

void SS2K::motorStop(bool releaseTension) {
  stepper->stopMove();
  stepper->setCurrentPosition(ss2k.targetPosition);
  if (releaseTension) {
    stepper->moveTo(ss2k.targetPosition - userConfig.getShiftStep() * 4);
  }
}

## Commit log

2021-08-02 Reverting to the old init method
    [BLE_Client.cpp]
2022-03-07 BLE updates
    arduino-esp32 switched to master
    switched cores for BLE client and setup
2022-12-14 corrections to body
    [ABS Shifter v5.f3d, ABS Shifter v7.f3d, body.3mf]
2023-01-07 replacing 3mf with stl
    [ABS Shifter v7.f3d, ABS Shifter v9.step, Body.stl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]
2023-04-02 Adjustable arms
    added as a mod
    [Bowflex C7.f3d, Bowflex C7.stl, Echelon Connect Sport.stl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]
2023-07-26 support for 39.4mm motor
    [3.5mmJack.SLDASM, 54-00063-1.SLDPRT, 54-00063-3.SLDPRT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]
2023-08-13 remove 39.4mm motor stl
    need to export new stls
    [Body_Left.STL, Body_Right.STL]
